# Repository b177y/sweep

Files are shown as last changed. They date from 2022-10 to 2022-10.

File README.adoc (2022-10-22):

= b177y Sweep
:imagesdir: docs/assets/images

Based on link:https://github.com/davidphilipbarr/Sweep[Ferris Sweep]
by link:https://github.com/davidphilipbarr[David Barr].

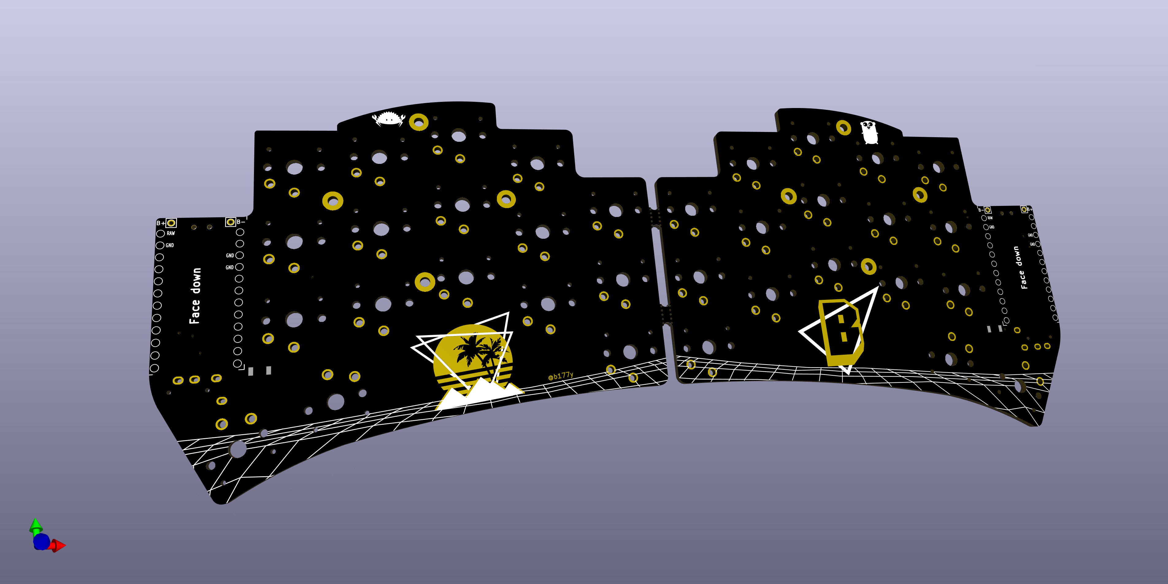
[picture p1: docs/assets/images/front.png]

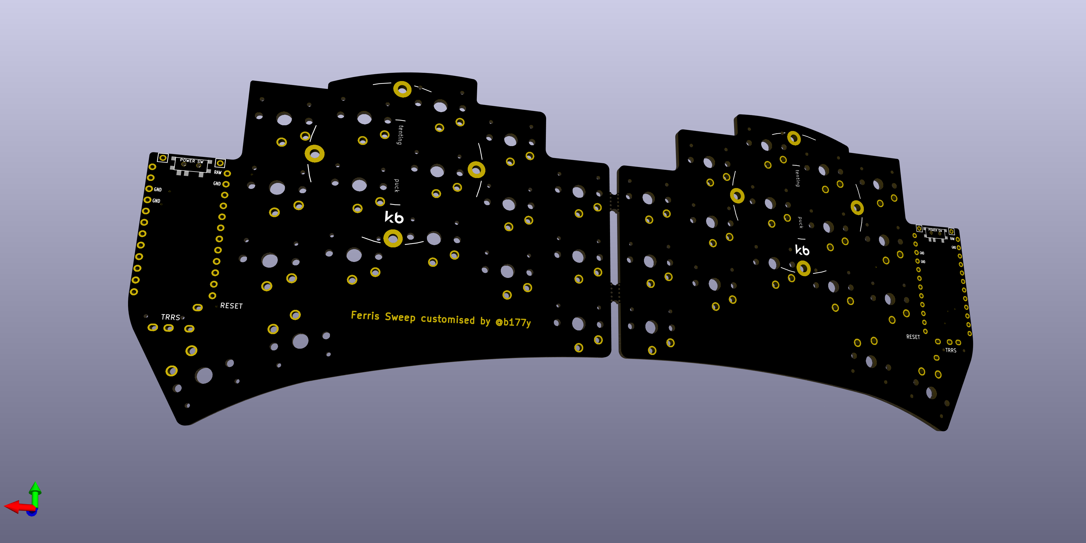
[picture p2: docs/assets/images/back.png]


This is the main Choc v1 board we all know and love.

== Ordering The PCB

To order the PCB the following settings are recommended
footnote:[Settings are for link:https://jlcpcb.com/[JLCPCB], but could work for other manufacturers.]
footnote:[Settings are taken from link:https://www.youtube.com/watch?v=fBPu7AyDtkM&t=17s[Kyek's video guide].]:

|===
|Detail |Value

|Gerber file
|`sweepv2.X_gerber.zip`

|Base material
|FR-4

|Layers
|2

|Dimension
|216.9mm x 86.9mm

|Different design
|2

|Delivery format
|Panel by customer

|PCB thickness
|1.6mm

|PCB color
|(Personal preference)

|Silkscreen
|(Personal preference)

|Surface finish
|(Personal preference)

|Outer copper weight
|1oz

|Gold Fingers
|No

|Confirm production file
|No

|Castellated holes
|No

|Remove order number
|Yes

|===

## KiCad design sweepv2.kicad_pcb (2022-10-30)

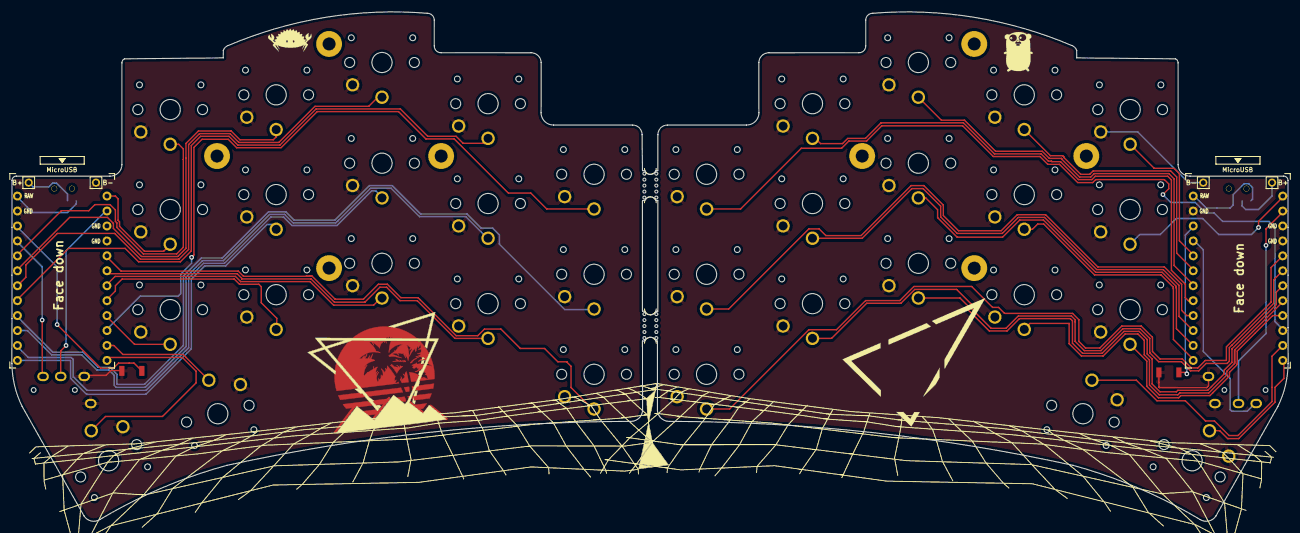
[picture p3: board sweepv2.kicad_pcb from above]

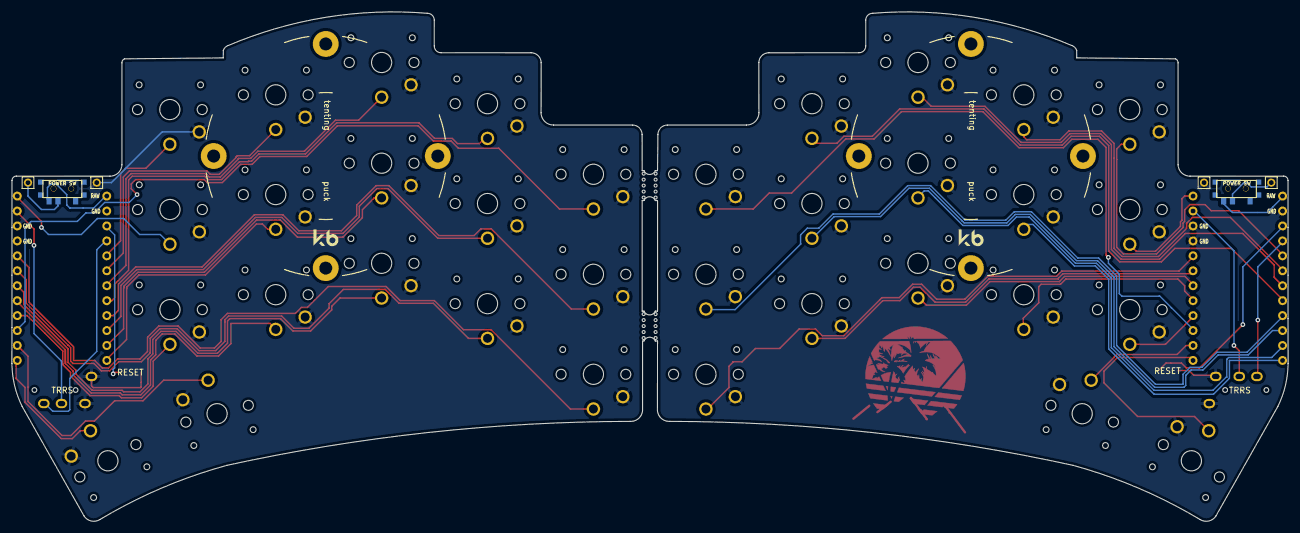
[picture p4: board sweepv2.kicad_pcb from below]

Board: 2 copper layers, 216.9 x 86.6 mm, 48 parts (2 on the bottom side), 43 nets.

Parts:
B+: MountingHole_Pad; 1pin_conn
B+#2: MountingHole_Pad; 1pin_conn
B-: MountingHole_Pad; 1pin_conn
B-#2: MountingHole_Pad; 1pin_conn
J1, J2: AudioJack4dpb; TRRS-PJ-320A
POWER SW: SW_SPDT; SPDT_C128955
POWER SW#2: SW_SPDT; SPDT_C128955
RSW1, RSW2: SW_Push; SW_SPST_B3U-1000P
SW2, SW2_r1, SW3, SW3_r1, SW4, SW4_r1, SW5, SW5_r1, SW6, SW6_r1, SW7_r1, SW8, SW8_r1, SW9, SW9_r1, SW10, SW11, SW11_r1, SW12, SW12_r1, SW13_r1, SW14, SW15, SW15_r1, SW16, SW16_r1, SW17, SW17_r1, SW18, SW18_r1, SW20, SW20_r1, SW21, SW21_r1: SW_Push; choc-v1-with-millmax
U1, U2: ProMicro-kbd; ProMicro_v3_min
mouse-bite-2mm-slot, mouse-bite-2mm-slot#2: VAL**; mouse-bite-5mm-slot-with-space-for-track

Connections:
BT+: B+#2.1, POWER SW#2.2
BT+_r: B+.1, POWER SW.2
Switch1: SW2.1, U1.10
Switch1_r: SW2_r1.1, U2.10
Switch2: SW3.1, U1.17
Switch2_r: SW3_r1.1, U2.17
Switch3: SW4.1, U1.18
Switch3_r: SW4_r1.1, U2.18
Switch4: SW5.1, U1.19
Switch4_r: SW5_r1.1, U2.19
Switch5: SW6.1, U1.20
Switch5_r: SW6_r1.1, U2.20
Switch6: SW8.1, U1.16
Switch6_r: SW7_r1.1, U2.16
Switch7: SW9.1, U1.15
Switch7_r: SW8_r1.1, U2.15
Switch8: SW10.1, U1.14
Switch8_r: SW9_r1.1, U2.14
Switch9: SW11.1, U1.13
Switch9_r: SW11_r1.1, U2.13
Switch10: SW12.1, U1.1
Switch10_r: SW12_r1.1, U2.1
Switch11: SW14.1, U1.5
Switch11_r: SW13_r1.1, U2.5
Switch12: SW15.1, U1.6
Switch12_r: SW18_r1.1, U2.6
Switch13: SW16.1, U1.7
Switch13_r: SW15_r1.1, U2.7
Switch14: SW17.1, U1.8
Switch14_r: SW16_r1.1, U2.8
Switch15: SW18.1, U1.9
Switch15_r: SW17_r1.1, U2.9
Switch16: SW21.1, U1.11
Switch16_r: SW21_r1.1, U2.11
Switch17: SW20.1, U1.12
Switch17_r: SW20_r1.1, U2.12
Switch18: J2.R1, U1.2
Switch18_r: J1.R1, U2.2
gnd: B-.1, B-#2.1, J1.S, J1.T, J2.S, J2.T, RSW1.1, RSW2.1, SW2.2, SW2_r1.2, SW3.2, SW3_r1.2, SW4.2, SW4_r1.2, SW5.2, SW5_r1.2, SW6.2, SW6_r1.2, SW7_r1.2, SW8.2, SW8_r1.2, SW9.2, SW9_r1.2, SW10.2, SW11.2, SW11_r1.2, SW12.2, SW12_r1.2, SW13_r1.2, SW14.2, SW15.2, SW15_r1.2, SW16.2, SW16_r1.2, SW17.2, SW17_r1.2, SW18.2, SW18_r1.2, SW20.2, SW20_r1.2, SW21.2, SW21_r1.2, U1.3, U1.4, U1.23, U2.3, U2.4, U2.23
raw: POWER SW.3, POWER SW#2.3, U1.24, U2.24
reset: RSW1.2, U1.22
reset_r: RSW2.2, U2.22
vcc: J1.R2, J2.R2, U1.21, U2.21

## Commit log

2022-10-22 Change cutout lines for PCB
    [sweepv2.kicad_pcb]
2022-10-22 Mirrored edge.cuts, kicad not recognising them as closed
    [sweepv2.kicad_pcb]
2022-10-23 started changing cutout, no errors
    [sweepv2.kicad_pcb]
2022-10-23 finish one side of cutout
    [sweepv2.kicad_pcb]
2022-10-23 Copy cutout to other half
    [sweepv2.kicad_pcb]
2022-10-23 Remove sweep logo, refill shape
    [sweepv2.kicad_pcb]
2022-10-23 remove tenting puck outlines from front
    [sweepv2.kicad_pcb]
2022-10-23 add geometrical synthwave to rhs
    [sweepv2.kicad_pcb]
2022-10-23 synthwave geometrical shape on both sides
    [sweepv2.kicad_pcb]
2022-10-23 Add basic logos to board
    [sweepv2.kicad_pcb]
2022-10-30 Remove B logo footprint
    [sweepv2.kicad_pcb]
2022-10-30 Add B logo with triangle
    [sweepv2.kicad_pcb]
2022-10-30 Add gopher, rustacean and name
    [sweepv2.kicad_pcb]
2022-10-30 Move synthwave down to avoid conflict with graphics
    [sweepv2.kicad_pcb]
